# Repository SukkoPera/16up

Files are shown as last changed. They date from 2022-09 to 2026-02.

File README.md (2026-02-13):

# 16UP
16UP is an Open Hardware Expansion board that will add a User Port to the Commodore 16, 116 and Plus/4 home computers.

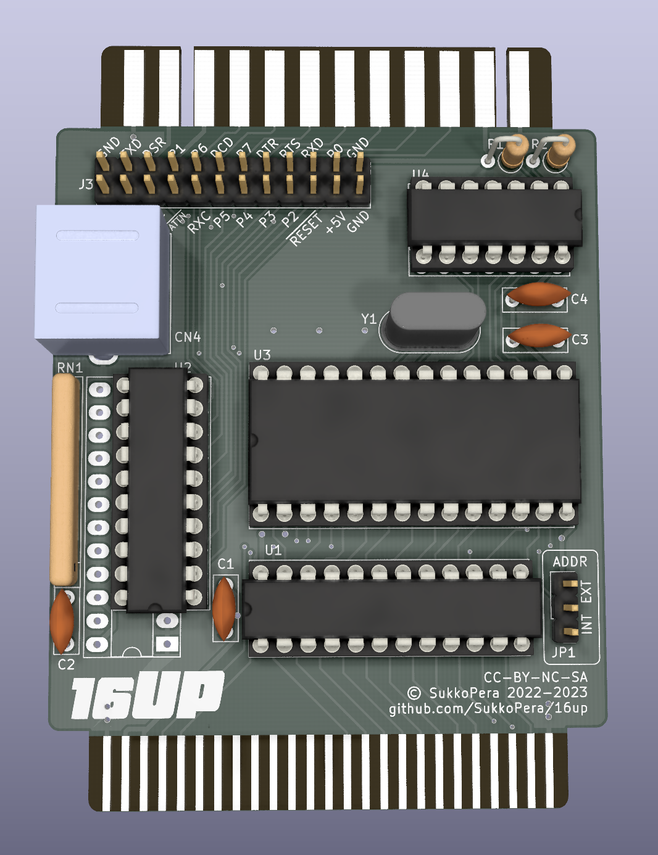
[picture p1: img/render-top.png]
Board


## Summary
The biggest difference between the Commodore 16/116 and the Plus/4, besides the different amount of RAM installed, is that the former lacks a User Port. In the past there were numerous attempts at making a cartridge for the Expansion Port that would fill this gap, but apparently none of them succeeded...

... None of them except this project, of course! :) 16UP will plug into the Expansion Port and "convert" it to a User Port that will be mostly compatible with that featured on the Plus/4. It can also be used on a Plus/4 in order to gain an extra User Port.

If you are interested in this board, **please read this document carefully**, there are a few aspects that you must be aware of.

## Versions
There are currently two usable versions of 16UP:
- [Version 2](https://github.com/SukkoPera/16up/releases/tag/v2) has an onboard fully-compliant RS-232 interface. Since the Plus/4 only provides TTL-level serial signals on the User Port, it requires an external plug-in board in order to turn those into a real RS-232 port. 16UP V2 already includes the converter but this implies that the serial signals are not provided on the User Port edge connector. This is generally not a problem as most peripherals that connect to the User Port only use the parallel port it provides, but peripherals have emerged, which use both the parallel and serial signals at the same time and these cannot of course work with V2.
- [Version 3](https://github.com/SukkoPera/16up/releases/tag/v3) was developed in order to be compatible with those peripherals. The onboard RS-232 converter was removed and now the board features an 87.5% Plus/4-compatible User Port: all signals are available on the edge connector right where they should be, except /ATTN and the 9VAC power rails. These signals can still be provided through a pin header, which was extended to cover all signals in order to also facilitate scoping and experimentation. [A plug-in board was developed](https://github.com/SukkoPera/Plus4Serial) for those who need RS-232 compatibility, while [another one](https://github.com/SukkoPera/Plus4Parallel) allows for a good degree of compatiblity with DB-25 PC-style parallel ports.

Both versions are valid and fully working, it is up to the user to choose what is best for them.

## Configuration
Both versions of 16UP can be configured to respond to two different address sets through the *JP1* jumper:

### External Address
This configuration will expose the ACIA (Serial port) at address `$fd6x` and the MOS 6529 (Parallel port) at `$fd7x`. These addresses are normally unused in both the C16/116 and +4, thus this setting is the most compatible, but it will need "special" software that either looks for the ports at these addresses or that allows the addresses to be configured manually.

On a +4, this configuration will effectively add a second User Port that can be used independently of the built-in one.

### Internal Address
This configuration will expose the ACIA and MOS 6529 at the same addresses that are normally used on a +4 (`$fd0x` for the ACIA and `$fd10` for the 6529). Of course this means that it cannot be used on a +4 as the port would conflict with the built-in one. It is rather meant to be used on a C16/116, making it ALMOST (see below) compatible with all the +4 software that uses the User Port.

**NOTE: Using this board on a C16/116 requires an internal modification in the machine. While this may sound impractical, it is fairly easy to perform and there are good reasons to perform it even if you are not interested in using this board. Please [see this page](https://github.com/SukkoPera/16up/wiki/Modification) for details.**

## Caveats
If you perform the C16/116 modification, plug 16UP in the Expansion Port and want to use the Datassette, you will notice that the computer will no longer detect when you press Play upon the *Press Play on tape* prompt. This is absolutely normal and is actually a sign that the modification works as intended. If you really want to use the Datassette you can either remove the board from the Expansion Port or make a Y cable with one female and two male MiniDIN-7 connectors: the Datassette will plug into the female connector, while one of the two male ones will plug into the C16/116 and the other one into the MiniDIN-7 connector on the 16up board.

Hint: if you want to save wire and effort, it is enough to bring the *Sense* signal ([Pin 6](doc/tapeport.png)) to the connector that plugs into 16UP.

Another hint: if you use [one of these](https://github.com/SukkoPera/OpenC64TapePortBreakOut) instead of the female connector, you can make an adapter for the C64 (1530) Datassette ;).

### V2-Only
Since all the serial signals are handled on-board, they are not brought out to the edge connector. Any peripheral that uses any signals besides P1-P8, /ATTN and /RESET just won't work with V2 and that's why V3 was developed.

## Compatibility
The +4 User Port is made up of a few distinct elements, let's analyze them one by one:

### 8-bit parallel port
The 8-bit parallel port can be implemented by a few different hardware components and is fully functional. There are a few caveats though:
- On V2, bit 1 is shared with the */CTS* serial port signal: this should not cause too much concern but you should be aware that it will be forced low whenever you have something connected to the serial port that is not ready to accept data. In this case, just disconnect the device or remove the *JP2* jumper (or set it to the *HW* position). Keep in mind that **bit 1 must be high before using the serial port** (or terminals will probably never know that the other end is ready to accept data), which is the case at reset/power-on.
- Bit 2 is shared with the *Cassette Sense* signal: if you have connected the Datassette Y cable to the board, whenever a key on it is pressed, bit 2 will be forced low. If you need to use the parallel port, press Stop on the Datassette in order to release all keys.

*(Do not blame me for the above, these are questionable design decisions straight from Commodore and those problems also affect a real +4.)*

### Serial port
The +4 User Port has all the signals required by an RS-232 interface, but they are at TTL voltage levels (i.e.: 0/+5V). This is fine if you need to connect a microcontroller like an Arduino but in order to turn them into a real RS-232 port, they need to be shifted to higher voltages.

#### V3
As already mentioned, you will need to use an [extra adapter](https://github.com/SukkoPera/Plus4Serial) that plugs into the User Port edge connector. 

#### V2
16UP V2 has such an adapter built-in and thus features a full RS-232 port on the onboard DE-9 connector.

All signals on the port are connected and usable, with the exception of *Ring Indicator*. *DCD*, *DSR* and */CTS* are pulled to the asserted level in order to allow communication with devices/cables that do not use those signals.

When using the serial port, you must decide whether you want hardware flow control to be handled by the ACIA or by the KERNAL: this might sound odd but it is due to the fact that ACIA chips of the era have an hardware bug that causes the */CTS* signal to be handled incorrectly. Commodore engineers must have found that out and decided to let the KERNAL handle it (if you look at the +4 schematics, you can clearly see that the signal was rerouted at a later stage). You can make your choice through the *JP2*/*JP3* jumpers (**always move them both to the same side!**): the *SW* setting will pass */CTS* to the KERNAL and is the recommended one as this is the configuration used on the +4. The *HW* position is only recommended if you are using a W65C51S chip (which should have fixed the bug) and is mainly meant as an experimental feature.

If you are looking for a terminal emulator, I recommend [Term-80](https://plus4world.powweb.com/software/Term-80_English) as it is hands down the most feature-rich program of its kind (Hint: press <kbd>CBM+HELP</kbd> when you get lost) and supports communication at 19200 bps (Take that, C64!).

### /RESET signal
This is fully functional as on the original +4.

### /ATTENTION signal
The /ATTENTION signal is not present on the C16/116 Expansion Port. Thus, if you need it, you will need to provide the board with it through the */ATTN* (*J1*) connector on V2 or through the relevant pin of the *J3* pin header on V3. The signal is available on pin 3 of the [IEC (Serial) port](doc/iec_serial.png) and it can be connected in parallel to any other device you already have on that port, just break it out.

### +5VDC power supply
This is directly connected to the main power rails of the C16/116. Use common sense and do not draw "too much" power out of it.

### 9VAC power supply
This is not present on the C16/116 Expansion Port and thus the corresponding pins of the User Port are left unconnected on V2, while on V3 they can be powered from the relevant pins of the *J3* pin header. This should not be a big deal though, as the main use case for this is to provide the higher voltages needed for a fully-compliant RS-232 interface but 16UP V2 has that built-in in a way that does not require an actual higher-voltage supply, and the same applies for the recommended adapter for V3. Let me know if you find any User Port peripherals that require it.

## Assembly
The parallel port on the +4 is driven through a MOS 6529 (U2 on the board). Since these days that IC is pretty hard to get hold of, an alternative circuit based on a 74LS654 was designed by Daniël Mantione and integrated into the board. Depending on what you choose to use:
- If you use an original MOS 6529: do NOT mount RN1.
- If you use a 74LS654: mount RN1.

There are various ICs that can be used as ACIA (U3):
- Original MOS 6551 or 8551 will work but are hard to find.
- The Western Design Center still produces the [W65C51S](https://www.westerndesigncenter.com/wdc/w65c51s-chip.php), which is based on the original MOS design and is fully compatible with it. There is also an -N model but its compatibility is uncertain at this stage.
- Older similar chips recovered from older equipment, such as the Rockwell R6551(A)P, UMC UM6551(A), etc. can be found on Aliexpress, eBay, etc. easily and cheaply and should be perfectly compatible. Prefer models with an *A* in the part number. I did all my testing with an R6551P, by the way.

The board uses a GAL for address decoding. Either a GAL20 or GAL22 can be used and both can be programmed with the ubiquitous TL866 programmers. The required JED files can be found in the relevant directories. The GAL speed shouldn't matter too much, I used a 25ns model with no particular issues.

## License
The 16UP documentation, including the design itself, is copyright &copy; SukkoPera 2022-2023 and is licensed under the [Creative Commons Attribution-NonCommercial-ShareAlike 4.0 International License](https://creativecommons.org/licenses/by-nc-sa/4.0/).

This documentation is distributed *as is* and WITHOUT ANY EXPRESS OR IMPLIED WARRANTIES whatsoever with respect to its functionality, operability or use, including, without limitation, any implied warranties OF MERCHANTABILITY, SATISFACTORY QUALITY, FITNESS FOR A PARTICULAR PURPOSE or infringement. We expressly disclaim any liability whatsoever for any direct, indirect, consequential, incidental or special damages, including, without limitation, lost revenues, lost profits, losses resulting from business interruption or loss of data, regardless of the form of action or legal theory under which the liability may be asserted, even if advised of the possibility or likelihood of such damages.

## Support the Project
If you want to get some boards manufactured, you can get them from PCBWay through this link:

### V2
PCB from PCBWay (https://www.pcbway.com/project/shareproject/16UP_User_Port_Cartridge_for_the_Commodore_16_116_and_Plus_4_2d0ad268.html)

### V3
PCB from PCBWay (https://www.pcbway.com/project/shareproject/16UP_V3_User_Port_Cartridge_for_the_Commodore_16_116_and_Plus_4_e4fbe888.html)

You get my gratitude and cheap, professionally-made and good quality PCBs, I get some credit that will help with this and [other projects](https://www.pcbway.com/project/member/shareproject/?bmbid=41100). You won't even have to worry about the various PCB options, it's all pre-configured for you!

Also, if you still have to register, [you can use this link](https://www.pcbway.com/setinvite.aspx?inviteid=41100) to get some bonus initial credit (and yield me some more).

You can also buy me a coffee if you want:



## Thanks
Inspiration for this board came from an uncompleted [project by Solder/Synergy](http://solder-synergy.de/plus4/hardware/index.html).

Other people from the [Plus/4 World Forum](https://plus4world.powweb.com/forum) helped, in particular:
* Daniël Mantione for the [MOS 6529 replacement circuit](https://www.sellmyretro.com/offer/details/mos-6529-spi-full-equivalent--_-soldering-kit-43923).
* TLC (Levente Hársfalvi) for lots of information about the serial port.
* MCes for helping fine-tuning of the C16 modification.

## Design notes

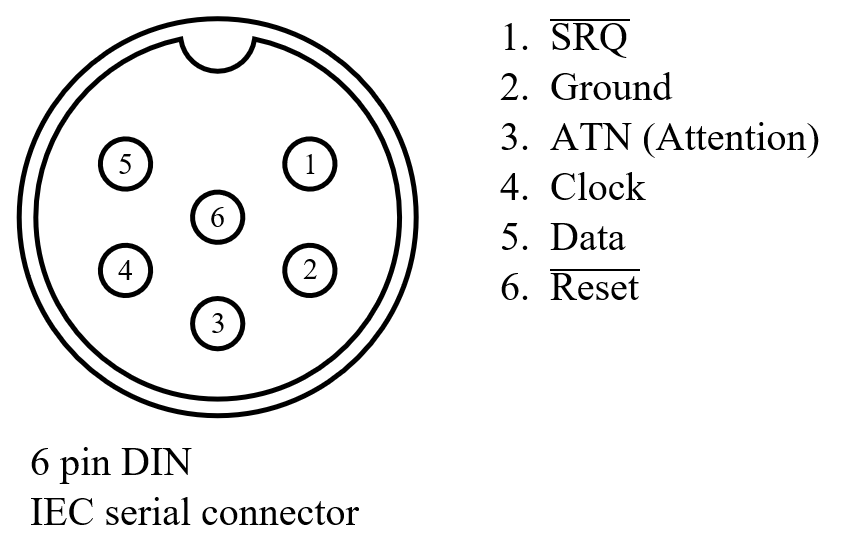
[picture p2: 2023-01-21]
doc/iec_serial.png

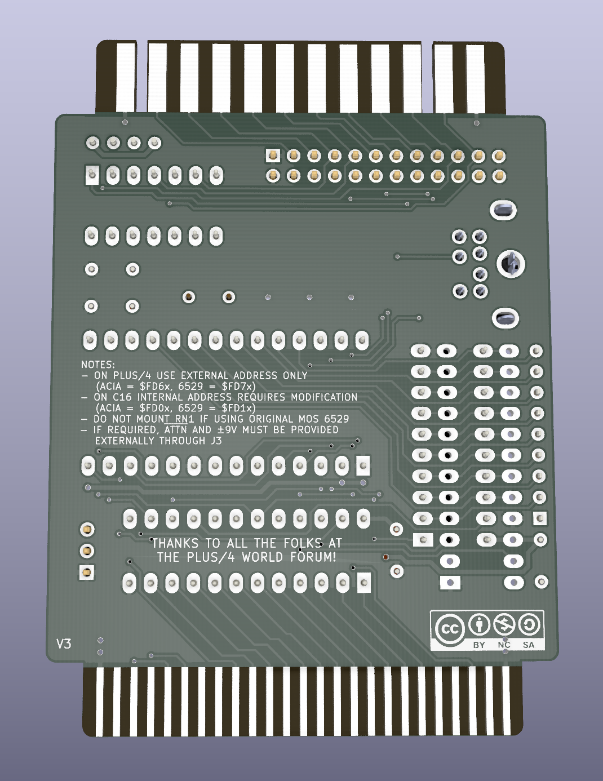
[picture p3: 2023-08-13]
img/render-bottom.png

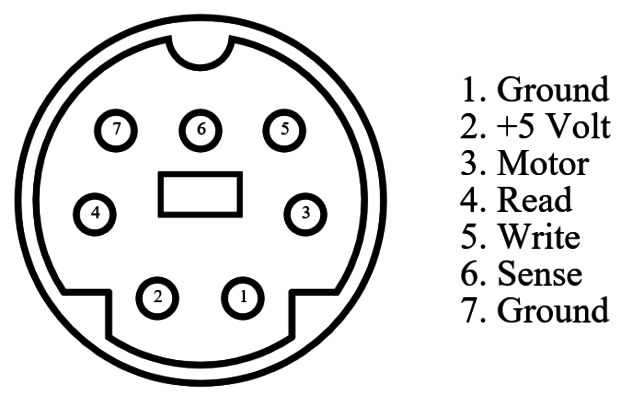
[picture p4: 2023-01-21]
doc/tapeport.png

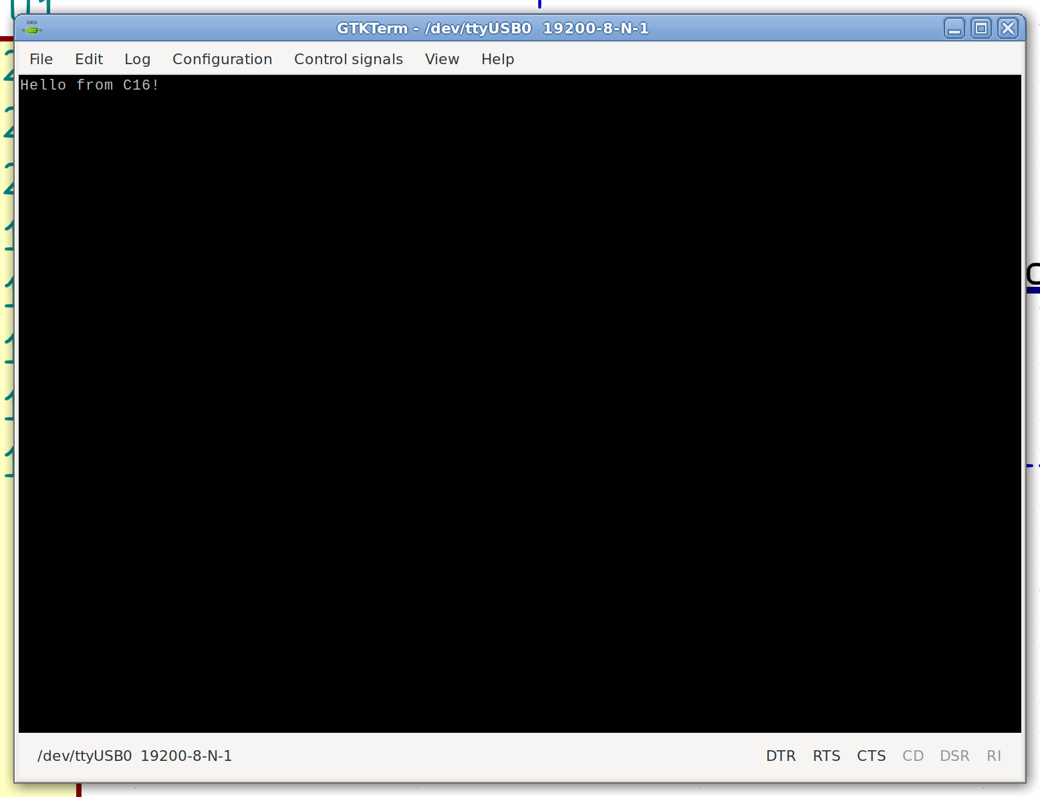
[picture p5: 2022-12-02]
img/c16_to_pc.png

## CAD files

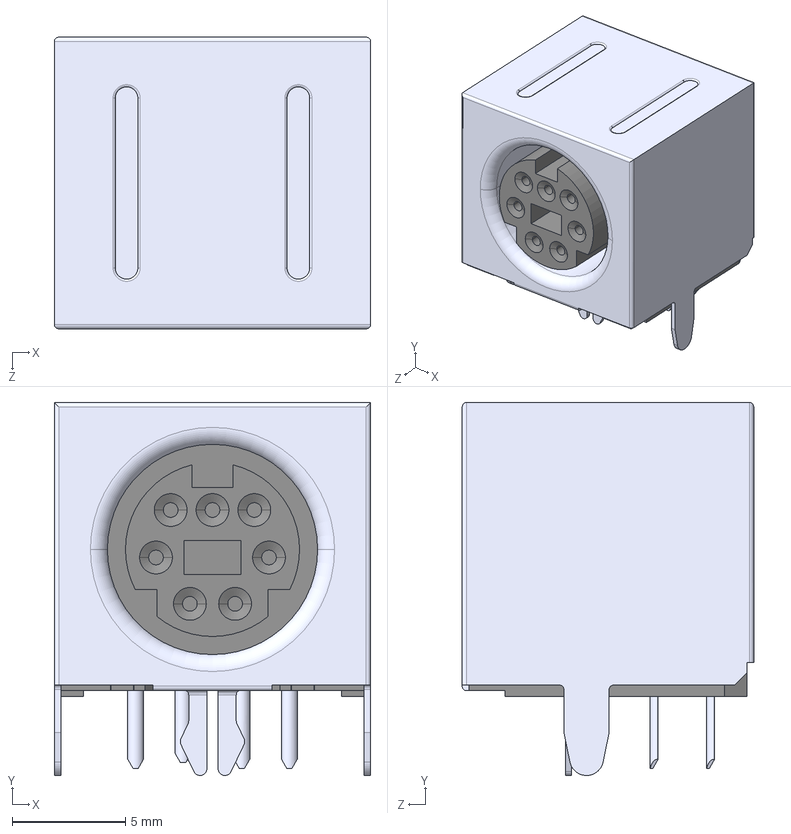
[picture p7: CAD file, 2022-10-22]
3dModels/KMDGX-7S-BS_rC6.step
14.0 x 16.5 x 12.9 mm

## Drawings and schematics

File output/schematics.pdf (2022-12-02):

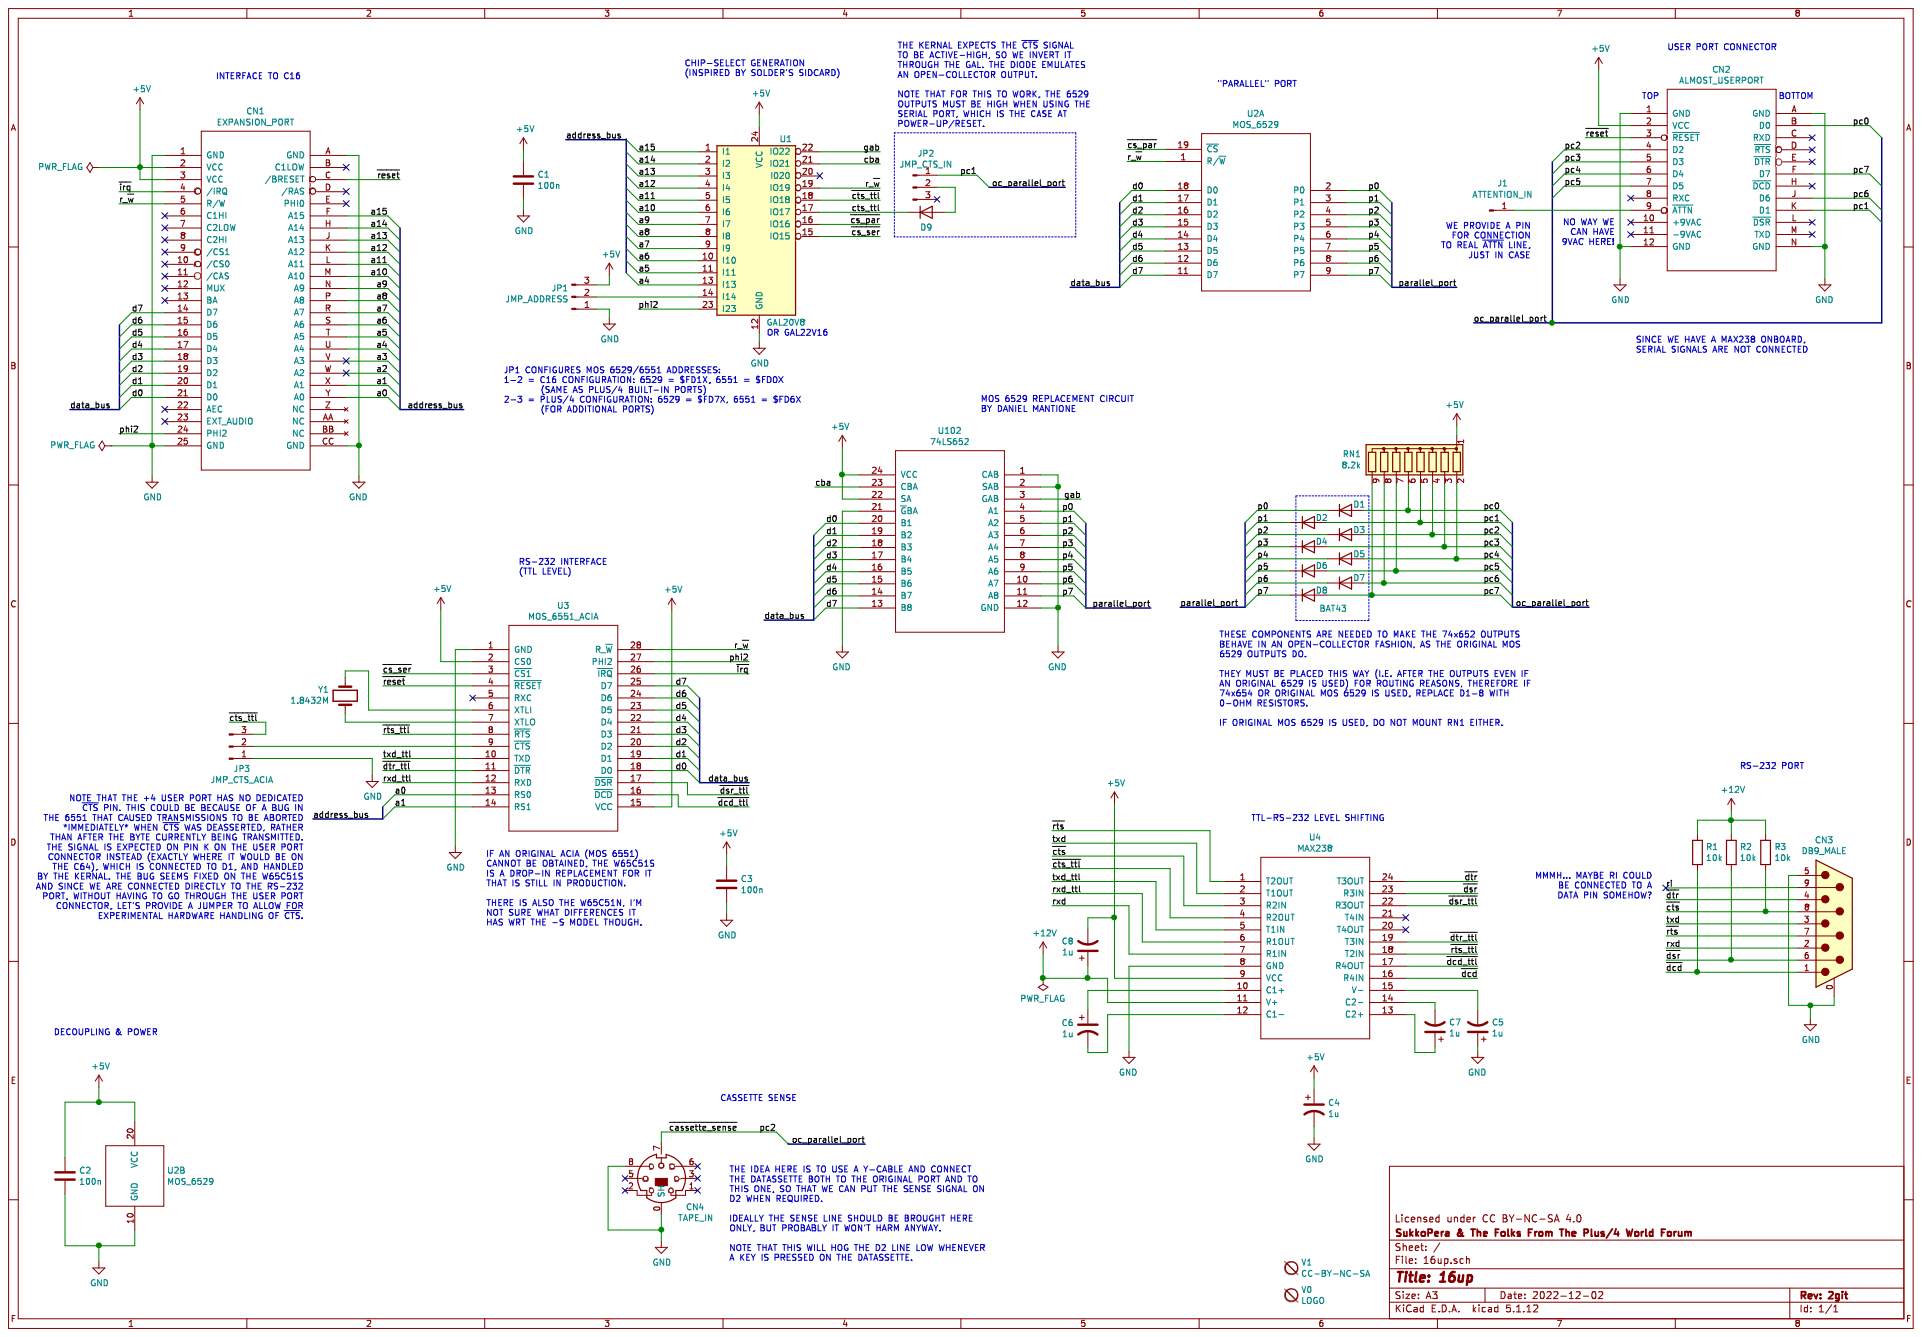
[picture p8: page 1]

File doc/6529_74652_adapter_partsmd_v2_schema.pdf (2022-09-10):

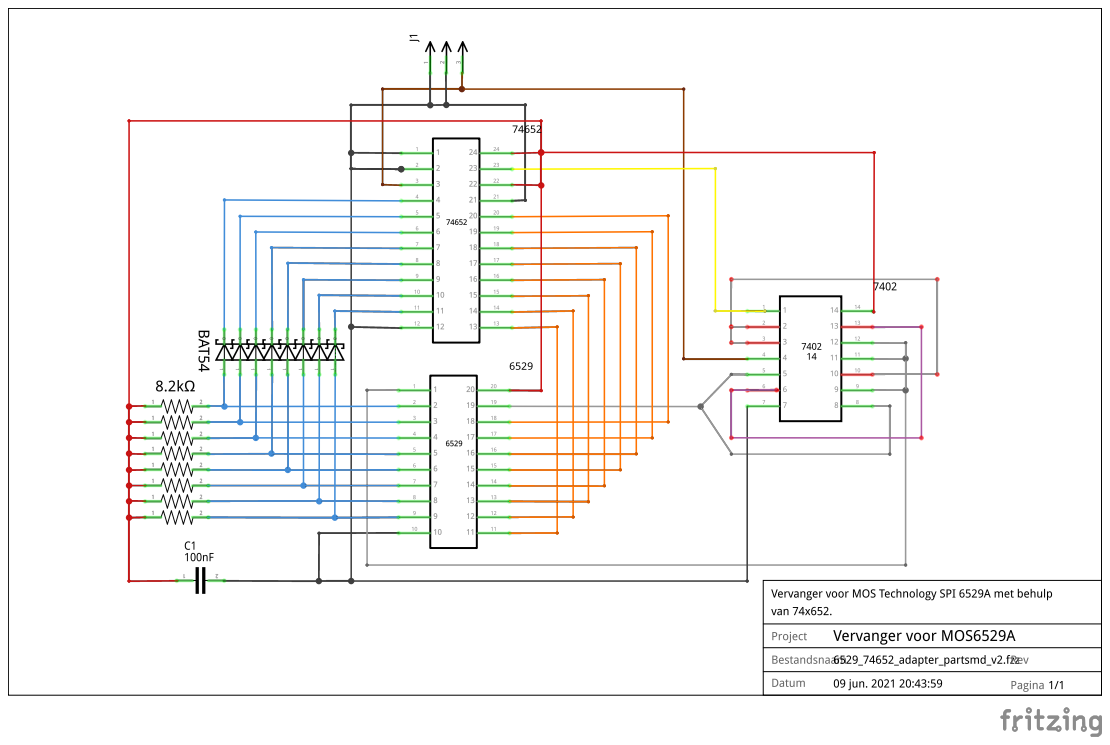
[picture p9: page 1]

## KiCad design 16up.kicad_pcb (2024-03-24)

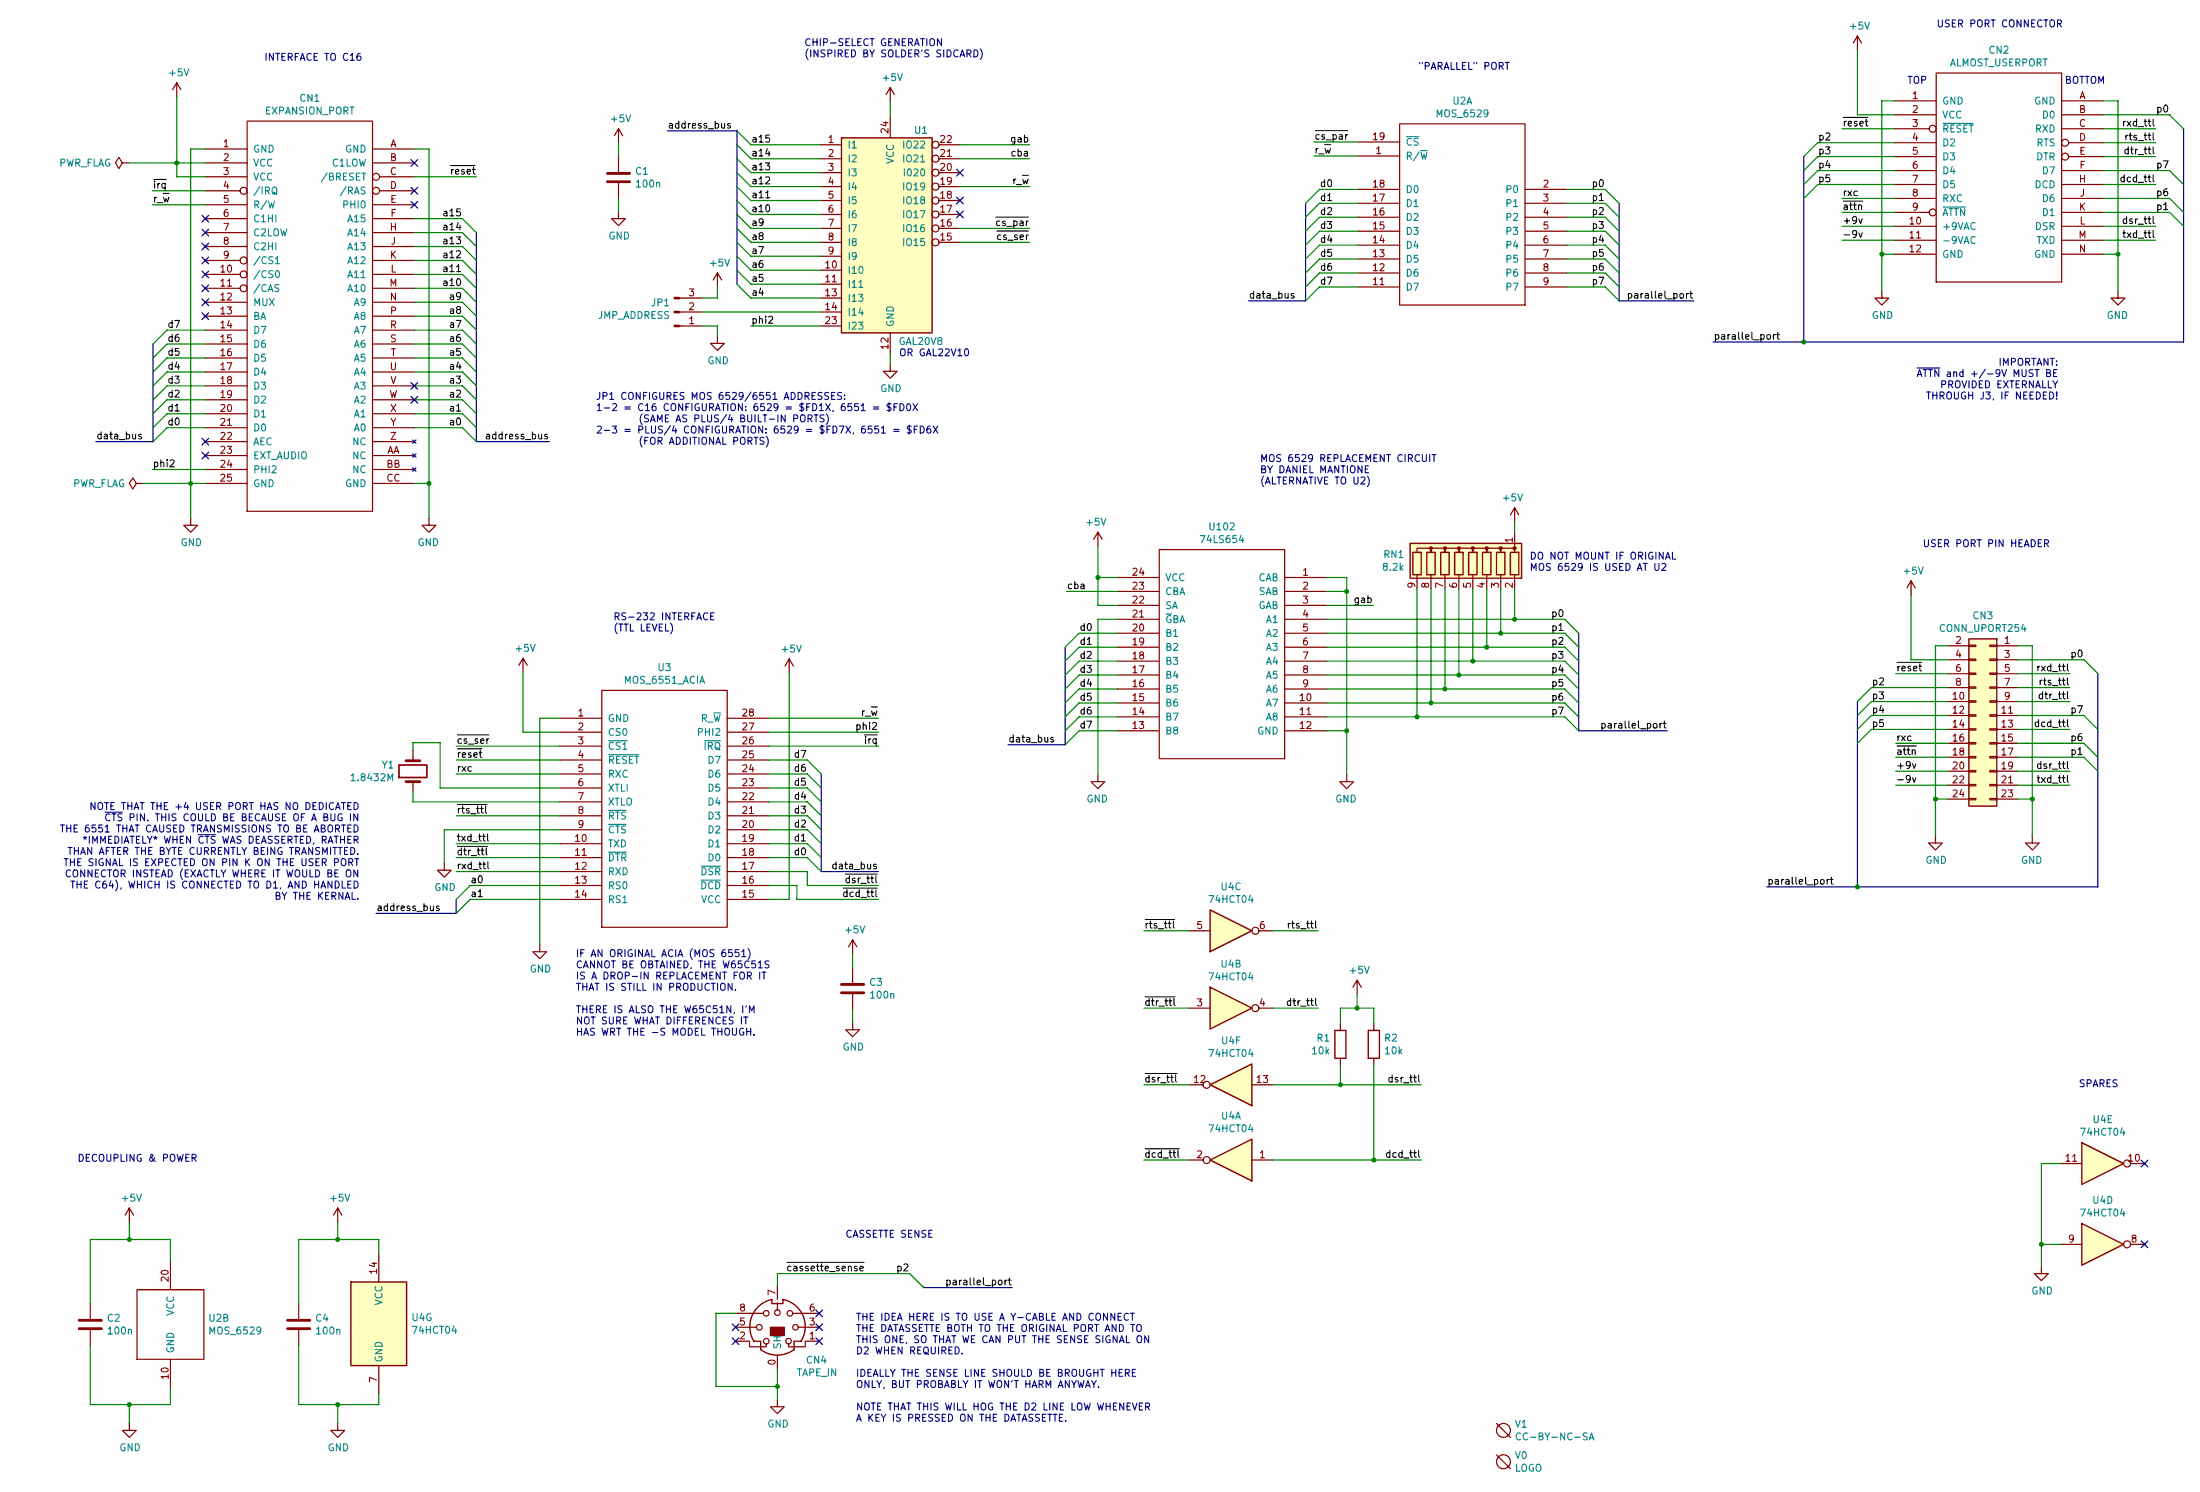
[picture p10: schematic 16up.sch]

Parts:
C1, C2, C3, C4: 100n; C_Disc_D7.0mm_W2.5mm_P5.00mm; MouserPN 810-FG28X7R1H104KNT0
CN1: EXPANSION_PORT; C16_Cart_Conn; MouserPN ---
CN2: ALMOST_USERPORT; Plus4_UserPort; MouserPN ---
CN3: CONN_UPORT254; PinHeader_2x12_P2.54mm_Vertical
CN4: TAPE_IN; KMDGX-7S-BS
JP1: JMP_ADDRESS; PinHeader_1x03_P2.54mm_Vertical
R1, R2: 10k; R_Axial_DIN0207_L6.3mm_D2.5mm_P2.54mm_Vertical
RN1: 8.2k; R_Array_SIP9
U1: GAL20V8; DIP-24_W7.62mm_Socket_LongPads; MouserPN 556-AF22V10C15PU
U2: MOS_6529; DIP-20_W7.62mm_Socket_LongPads
U3: MOS_6551_ACIA; DIP-28_W15.24mm_Socket_LongPads
U4: 74HCT04; DIP-14_W7.62mm_Socket_LongPads
U102: 74LS654; DIP-24_W7.62mm_Socket_LongPads
V0: LOGO; logo; MouserPN ---
V1: CC-BY-NC-SA; cc_by_nc_sa; MouserPN ---
Y1: 1.8432M; Crystal_HC49-U_Vertical; MouserPN 520-HCA184-SX

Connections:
+5V: C1.1, C2.1, C3.1, C4.1, CN1.2 (VCC), CN1.3 (VCC), CN2.2 (VCC), CN3.4, JP1.3, R1.2, R2.1, RN1.1 (common), U1.24 (VCC), U2.20 (VCC), U3.2 (CS0), U3.15 (VCC), U4.14 (VCC), U102.22 (SA), U102.24 (VCC)
/+9v: CN2.10 (+9VAC), CN3.20
/-9v: CN2.11 (-9VAC), CN3.22
/a0: CN1.Y (A0), U3.13 (RS0)
/a1: CN1.X (A1), U3.14 (RS1)
/a2: CN1.W (A2)
/a3: CN1.V (A3)
/a4: CN1.U (A4), U1.13 (I13)
/a5: CN1.T (A5), U1.11 (I11)
/a6: CN1.S (A6), U1.10 (I10)
/a7: CN1.R (A7), U1.9 (I9)
/a8: CN1.P (A8), U1.8 (I8)
/a9: CN1.N (A9), U1.7 (I7)
/a10: CN1.M (A10), U1.6 (I6)
/a11: CN1.L (A11), U1.5 (I5)
/a12: CN1.K (A12), U1.4 (I4)
/a13: CN1.J (A13), U1.3 (I3)
/a14: CN1.H (A14), U1.2 (I2)
/a15: CN1.F (A15), U1.1 (I1)
/cba: U1.21 (IO21), U102.23 (CBA)
/d0: CN1.21 (D0), U2.18 (D0), U3.18 (D0), U102.20 (B1)
/d1: CN1.20 (D1), U2.17 (D1), U3.19 (D1), U102.19 (B2)
/d2: CN1.19 (D2), U2.16 (D2), U3.20 (D2), U102.18 (B3)
/d3: CN1.18 (D3), U2.15 (D3), U3.21 (D3), U102.17 (B4)
/d4: CN1.17 (D4), U2.14 (D4), U3.22 (D4), U102.16 (B5)
/d5: CN1.16 (D5), U2.13 (D5), U3.23 (D5), U102.15 (B6)
/d6: CN1.15 (D6), U2.12 (D6), U3.24 (D6), U102.14 (B7)
/d7: CN1.14 (D7), U2.11 (D7), U3.25 (D7), U102.13 (B8)
/dcd_ttl: CN2.H (DCD), CN3.13, R2.2, U4.1
/dsr_ttl: CN2.L (DSR), CN3.19, R1.1, U4.13
/dtr_ttl: CN2.E (DTR), CN3.9, U4.4
/gab: U1.22 (IO22), U102.3 (GAB)
/p0: CN2.B (D0), CN3.3, RN1.2 (R1), U2.2 (P0), U102.4 (A1)
/p1: CN2.K (D1), CN3.17, RN1.3 (R2), U2.3 (P1), U102.5 (A2)
/p2: CN2.4 (D2), CN3.8, CN4.7, RN1.4 (R3), U2.4 (P2), U102.6 (A3)
/p3: CN2.5 (D3), CN3.10, RN1.5 (R4), U2.5 (P3), U102.7 (A4)
/p4: CN2.6 (D4), CN3.12, RN1.6 (R5), U2.6 (P4), U102.8 (A5)
/p5: CN2.7 (D5), CN3.14, RN1.7 (R6), U2.7 (P5), U102.9 (A6)
/p6: CN2.J (D6), CN3.15, RN1.8 (R7), U2.8 (P6), U102.10 (A7)
/p7: CN2.F (D7), CN3.11, RN1.9 (R8), U2.9 (P7), U102.11 (A8)
/phi2: CN1.24 (PHI2), U1.23 (I23), U3.27 (PHI2)
/r_~w: CN1.5 (R/W), U1.19 (IO19), U2.1 (R/~W), U3.28 (R_~W)
/rts_ttl: CN2.D (RTS), CN3.7, U4.6
/rxc: CN2.8 (RXC), CN3.16, U3.5 (RXC)
/rxd_ttl: CN2.C (RXD), CN3.5, U3.12 (RXD)
/txd_ttl: CN2.M (TXD), CN3.21, U3.10 (TXD)
/~attn: CN2.9 (~ATTN), CN3.18
/~cs_par: U1.16 (IO16), U2.19 (~CS)
/~cs_ser: U1.15 (IO15), U3.3 (~CS1)
/~dcd_ttl: U3.16 (~DCD), U4.2
/~dsr_ttl: U3.17 (~DSR), U4.12
/~dtr_ttl: U3.11 (~DTR), U4.3
/~irq: CN1.4 (/IRQ), U3.26 (~IRQ)
/~reset: CN1.C (/BRESET), CN2.3 (~RESET), CN3.6, U3.4 (~RESET)
/~rts_ttl: U3.8 (~RTS), U4.5
GND: C1.2, C2.2, C3.2, C4.2, CN1.1 (GND), CN1.25 (GND), CN1.A (GND), CN1.CC (GND), CN2.1 (GND), CN2.12 (GND), CN2.A (GND), CN2.N (GND), CN3.1, CN3.2, CN3.23, CN3.24, CN4.0 (SH), CN4.8, JP1.1, U1.12 (GND), U2.10 (GND), U3.1 (GND), U3.9 (~CTS), U4.7 (GND), U4.9, U4.11, U102.1 (CAB), U102.2 (SAB), U102.12 (GND), U102.21 (~G~BA)
unnamed: JP1.2, U1.14 (I14)
unnamed: U3.6 (XTLI), Y1.2
unnamed: U3.7 (XTLO), Y1.1

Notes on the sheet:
CHIP-SELECT GENERATION (INSPIRED BY SOLDER'S SIDCARD)
IMPORTANT: ~ATTN~ and +/-9V MUST BE PROVIDED EXTERNALLY THROUGH J3, IF NEEDED!
"PARALLEL" PORT
USER PORT CONNECTOR
INTERFACE TO C16
NOTE THAT THE +4 USER PORT HAS NO DEDICATED ~CTS~ PIN. THIS COULD BE BECAUSE OF A BUG IN THE 6551 THAT CAUSED TRANSMISSIONS TO BE ABORTED *IMMEDIATELY* WHEN ~CTS~ WAS DEASSERTED, RATHER THAN AFTER THE BYTE CURRENTLY BEING TRANSMITTED. THE SIGNAL IS EXPECTED ON PIN K ON THE USER PORT CONNECTOR INSTE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
IF AN ORIGINAL ACIA (MOS 6551) CANNOT BE OBTAINED, THE W65C51S IS A DROP-IN REPLACEMENT FOR IT THAT IS STILL IN PRODUCTION. THERE IS ALSO THE W65C51N, I'M NOT SURE WHAT DIFFERENCES IT HAS WRT THE -S MODEL THOUGH.
RS-232 INTERFACE (TTL LEVEL)
DECOUPLING & POWER
TOP
BOTTOM
JP1 CONFIGURES MOS 6529/6551 ADDRESSES: 1-2 = C16 CONFIGURATION: 6529 = $FD1X, 6551 = $FD0X (SAME AS PLUS/4 BUILT-IN PORTS) 2-3 = PLUS/4 CONFIGURATION: 6529 = $FD7X, 6551 = $FD6X (FOR ADDITIONAL PORTS)
OR GAL22V10
CASSETTE SENSE
THE IDEA HERE IS TO USE A Y-CABLE AND CONNECT THE DATASSETTE BOTH TO THE ORIGINAL PORT AND TO THIS ONE, SO THAT WE CAN PUT THE SENSE SIGNAL ON D2 WHEN REQUIRED. IDEALLY THE SENSE LINE SHOULD BE BROUGHT HERE ONLY, BUT PROBABLY IT WON'T HARM ANYWAY. NOTE THAT THIS WILL HOG THE D2 LINE LOW WHENEVER A 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
SPARES
USER PORT PIN HEADER
DO NOT MOUNT IF ORIGINAL MOS 6529 IS USED AT U2
MOS 6529 REPLACEMENT CIRCUIT BY DANIEL MANTIONE (ALTERNATIVE TO U2)

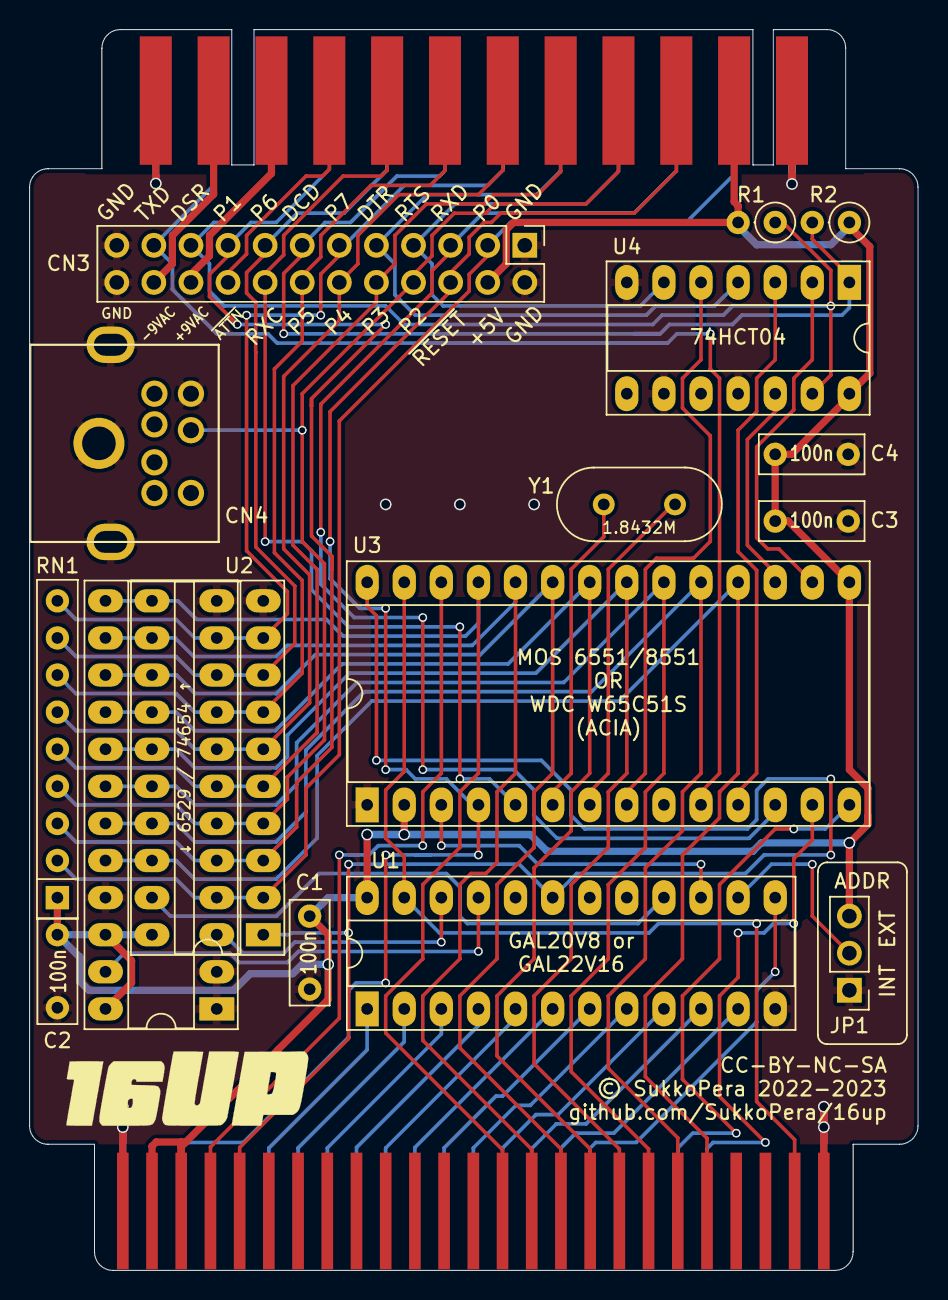
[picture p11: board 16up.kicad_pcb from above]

Board: 2 copper layers, 60.8 x 85.0 mm, 20 parts (1 on the bottom side), 57 nets.

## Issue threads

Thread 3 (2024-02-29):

Is it 74LS652 or 74LS654

nsinav, 2024-02-29:
Hello:

I am trying to get all the components of this project but i have some questions:

1) Is it 74LS652 or 74LS654? BOM says 652 but the text on github says 654.

2) where i can find this component?

3) 2) 74LS647 is compatible ?

Thank you

SukkoPera, 2024-02-29:
You need a 654. If BOM says 652 it needs to be corrected. 647 is not compatible.

Unfortunately TI discontinued it right after I released this, very good timing. I suggest looking for it on eBay.

Or you can get a MOS6529. You might still find some here and there.

nsinav, 2024-02-29:
Thank you. I see the project has discontinued parts. Too bad i recently get the PCB on PCBWay and the chips on ebay are very expensive.

SukkoPera, 2024-02-29:
That's retro stuff, you have to bear with that. I'd happily welcome any modifications to the board that adapt it to a chip that's currently available.

Anyway you can still get 654s at a decent price: https://www.ebay.it/itm/152038427690.

nsinav, 2024-02-29:
I understand this is retro stuff, i read all the documentation but i never get the 74LS654 it's an obsolete chip.

And by other hand, yeah sure, very decent price. Look the shipping costs. It's freaking huge.

Thanks

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

SukkoPera, 2024-02-29:
Come on, get in touch with them and talk about it. They won't need to spend 60€ to ship a couple of chips to wherever you live. The price is clearly estimated for larger orders.

Otherwise MOS6529 is relatively easy to find at around 10€/each and you have multiple sources.

nsinav, 2024-02-29:
Yes i an trying to get in touch with them i get a real quote of the shipping. Thank you.

Closed 2024-03-24.

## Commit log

2022-09-02 Assign footprints
    [ExtraUserPort.kicad_pcb, ExtraUserPort.sch]
2022-09-04 Fix some warnings
    [ExtraUserPort.kicad_pcb, ExtraUserPort.sch]
2022-09-04 (Very) Rough routing done
    [ExtraUserPort.kicad_pcb, ExtraUserPort.sch]
2022-09-06 Improve routing
    [ExtraUserPort.kicad_pcb, ExtraUserPort.sch]
2022-09-06 Almost there
    [ExtraUserPort.kicad_pcb]
2022-09-07 Swap top/bottom pins of edge connector Sigh...
    [ExtraUserPort.kicad_pcb, ExtraUserPort.sch]
2022-09-13 Move /CTS to PC2
    [ExtraUserPort.kicad_pcb, ExtraUserPort.sch]
2022-09-17 Almost ready for prototypes
    [ExtraUserPort.kicad_pcb, ExtraUserPort.sch]
2022-09-17 Final touches
    [ExtraUserPort.kicad_pcb, ExtraUserPort.sch]
2022-09-17 ExtraUserPort -> 16up
    [16up.kicad_pcb, 16up.sch]
2022-09-18 Fix userport connector !!!
    [16up.kicad_pcb, 16up.sch]
2022-09-18 Add schematics PDF
2022-09-21 Remove serial signals from Userport connector They wouldn't work anyway, as whatever gets connected there expects all control signals to be inverted as per Commodore serial port standards.
    [16up.kicad_pcb, 16up.sch]
2022-09-28 Pull-up signals at the RS-232 port
    [16up.kicad_pcb, 16up.sch]
2022-10-17 Get rid of protruding track
    [16up.kicad_pcb]
2022-10-17 Add C2 value on silkscreen
    [16up.kicad_pcb]
2022-10-22 Fix /CTS
    [16up.kicad_pcb, 16up.sch]
2022-10-22 Use better MiniDIN-7 footprint The former was actually a MiniDIN-8...
    [16up.kicad_pcb, 16up.sch, KMDGX-7S-BS_rC6.step]
2022-10-23 Fix track alignment
    [16up.kicad_pcb]
2022-12-02 Move crystal above U3 for easier insertion These crystals are always too tall...
    [16up.kicad_pcb]
2022-12-02 Improve ground plane
    [16up.kicad_pcb, 16up.sch]
2022-12-07 Only support 74x654 as 6529 replacement
    [16up.kicad_pcb, 16up.sch]
2023-03-07 Start 232-less version
    [16up.kicad_pcb, 16up.sch]
2023-03-13 Routing done
    [16up.kicad_pcb, 16up.sch]
2023-03-13 Ground unused gates of U4
    [16up.kicad_pcb, 16up.sch]
2023-03-15 Do not let soldermask between fingers of top connector
    [16up.kicad_pcb]
2023-08-13 Update renders and board link
2024-03-24 Close #3
    [16up.kicad_pcb, 16up.sch]

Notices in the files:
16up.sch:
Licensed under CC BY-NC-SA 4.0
